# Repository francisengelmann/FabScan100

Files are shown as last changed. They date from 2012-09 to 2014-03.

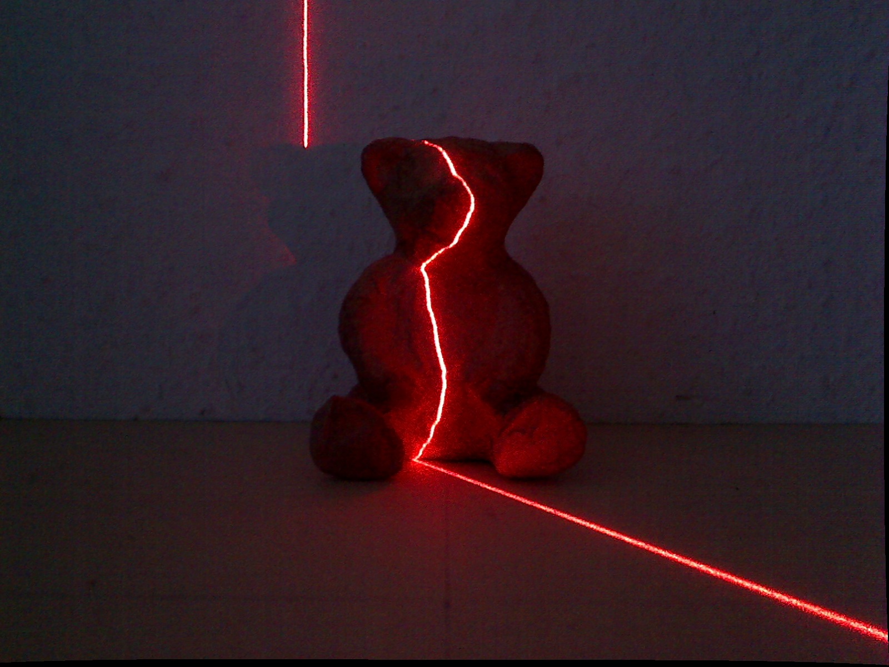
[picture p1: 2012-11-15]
qtTest/laser_on.jpg

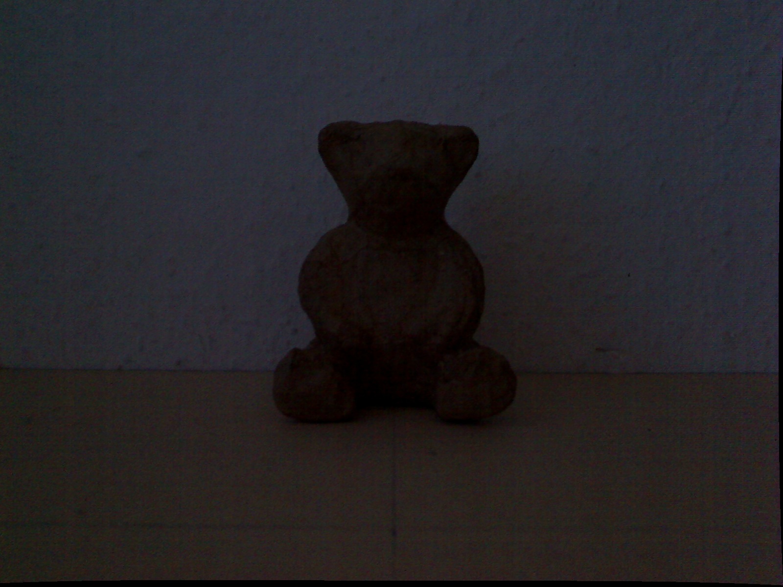
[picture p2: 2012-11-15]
qtTest/laser_off.jpg

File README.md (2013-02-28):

FabScan100
==========
The FabScan100 software is planned to run on Mac and Linux (and maybe also Windows).
This git repository stores all the files for the project, software as well as the hardware.

Also check these links for more information:
* http://hci.rwth-aachen.de/fabscan100
* http://groups.google.com/group/fabscan

Progress
========

FabScan100 is now functional! Runs on Mac and Ubuntu, still needs to be ported to Windows.

Current Setup on Mac: Qt 5.0.1 with Qt-Creator 2.6.2

Current Setup on Ubuntu: Qt 5.0.1 with Qt-Creator 2.6.2 

Current Setup on Windows: not tested, who wants to do this ?

Qt 4.8 is needed for QGLFunctions.

Installation
===========

Install "Qt Creator" and "Qt Libraries Qt 5.0" from http://qt-project.org/downloads.
Make sure you have OpenGL installed. Preinstalled on Ubuntu, Mac. What about Windows?

Mac OS X 10.8.2 with XCode 4.6 installed
========================================
1. Install Homebrew: http://mxcl.github.com/homebrew/
The next steps need to be executed in Terminal.
Terminal is located in Applications/Utilities/Terminal.app
2. Install OpenCV using homebrew: brew install opencv
3. Install Boost: brew install boost
4. Install FLANN: brew install flann
5. Install VTK: brew install vtk
6. Install eigen: brew install eigen
7. Install the experimental version from trunck of PCL 1.7

  * svn co http://svn.pointclouds.org/pcl/trunk pcl-trunk
  * cd pcl-trunk && mkdir build && cd build
  * cmake -DCMAKE_BUILD_TYPE=Release .. 
  * make
  * sudo make install

At this point we have installed all the dependencies needed for FabScan. We can now proceed to actually compiling FabScan:

8. Install git which is a tool to access source repositories: brew install git
9. Then download the code using git: git clone git://github.com/francisengelmann/FabScan100.git
10. Open qtTest/qtTest.pro in "Qt Creator".
11. If asked select "Qt 5.0.1" Kit, then click "Configure Project".
12. In the left panel, click on "Projects", then "Manage Kits". Select from AutoDetected "Qt5.0.1", click clone, then in the "Compiler" popupmenu select "GCC x86 64bit". Then press OK to exit.
13. Again in the "Projects" tab, select the newly created Kit from the "Add Kit" popupmenu.
14. Run the project by clicking on the green arrow on the bottom left.
15. Wait for it to compile, this can take a few minutes.
 
Ubuntu 12.10:
=======
1. Install Qt
  * Install Qt-5.0.1 libraries http://qt-project.org/downloads

2. Install OpenCV (inspired from http://www.samontab.com/web/2012/06/installing-opencv-2-4-1-ubuntu-12-04-lts/)
  * sudo apt-get update
  * sudo apt-get upgrade
  * sudo apt-get install libeigen3-dev build-essential libgtk2.0-dev libjpeg-dev libtiff4-dev libjasper-dev libopenexr-dev cmake python-dev python-numpy python-tk libtbb-dev yasm libfaac-dev libopencore-amrnb-dev libopencore-amrwb-dev libtheora-dev libvorbis-dev libxvidcore-dev libx264-dev sphinx-common texlive-latex-extra libv4l-dev libdc1394-22-dev libavcodec-dev libavformat-dev libswscale-dev

  * cd ~
  * wget http://downloads.sourceforge.net/project/opencvlibrary/opencv-unix/2.4.4/OpenCV-2.4.4-beta.tar.bz2
  * tar -xvf OpenCV-2.4.4-beta.tar.bz2
  * cd OpenCV-2.4.4

  * mkdir build
  * cd build
  * cmake -D WITH_TBB=ON -D BUILD_NEW_PYTHON_SUPPORT=ON -D WITH_V4L=ON -D INSTALL_C_EXAMPLES=OFF -D INSTALL_PYTHON_EXAMPLES=OFF -D BUILD_EXAMPLES=OFF -D WITH_QT=ON -D WITH_OPENGL=ON ..
  
3. Install PCL
  * sudo add-apt-repository ppa:v-launchpad-jochen-sprickerhof-de/pcl
  * sudo apt-get update
  * sudo apt-get install libpcl-all

4. Install uvccapture
  * sudo apt-get install uvccapture
  * to test run the following command: uvccapture -d/dev/video0 -oshot.jpg

5. Give permissions for serial port
  * sudo adduser USER_NAME dialout
  * log out and back in

Windows:
========
People are working on this :)
 
Other platforms
===============

Make sure to adapt the .pro file e.g. correct lib and header pathes.

Get the source code
===================

In order to compile the code you need git:
Mac: brew install git
Ubunutu: sudo apt-get install git
Windows: ?

To get read-only access to the code, type into the console:
git clone git://github.com/francisengelmann/FabScan100.git

If you also want to modify the code please send me an email with your ssh public key so i can give you access.

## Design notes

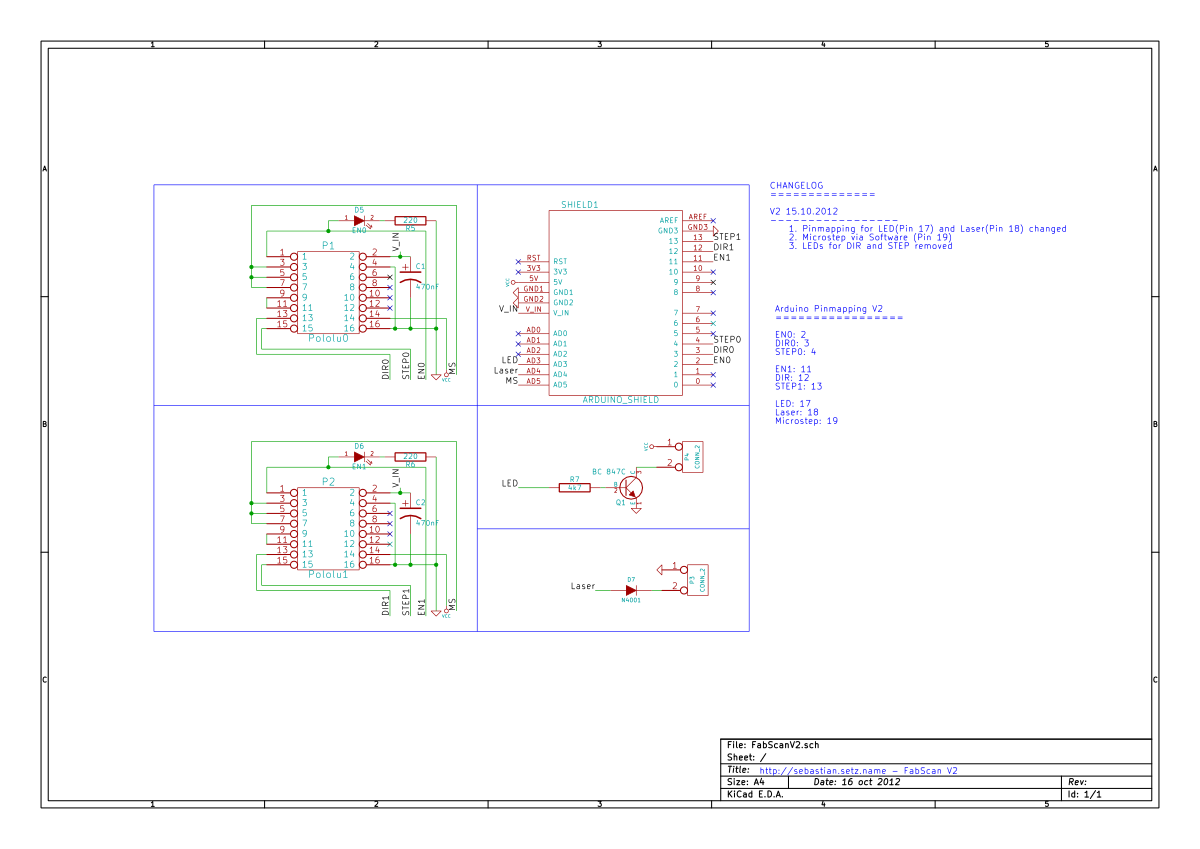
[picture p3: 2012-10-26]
arduino/FabScanModV2_Schematic.png

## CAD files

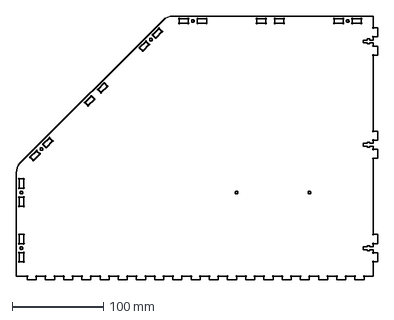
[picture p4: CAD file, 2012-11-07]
lasercutter/BoxLeftSide.dxf
397.0 x 290.0 mm

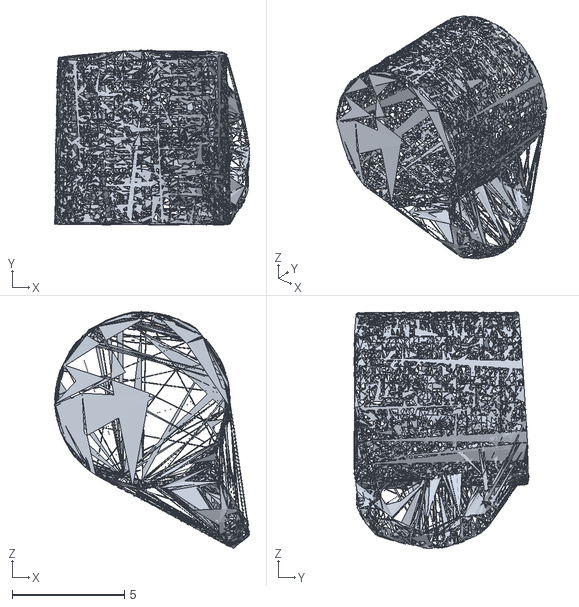
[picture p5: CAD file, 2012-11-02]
scans/bigCub/bigCub.stl
8.67 x 7.75 x 10.5

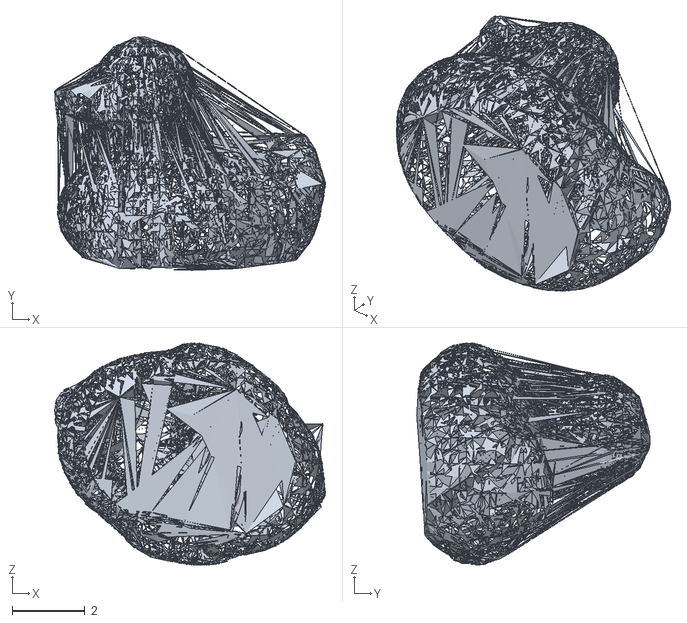
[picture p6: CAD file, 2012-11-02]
scans/bigDuck/bigDuck.stl
7.44 x 6.41 x 6.09

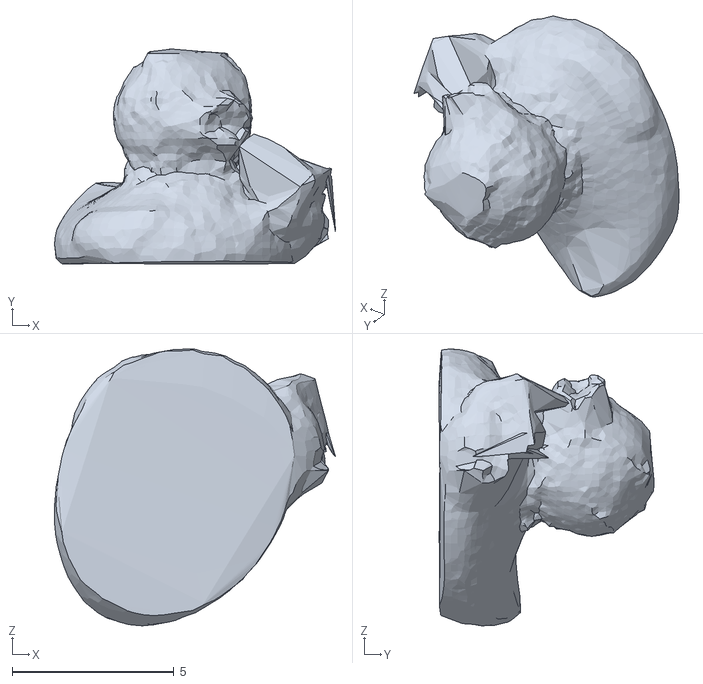
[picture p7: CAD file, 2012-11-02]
scans/laptopDuck/laptopDuck.ply
8.69 x 6.64 x 8.56

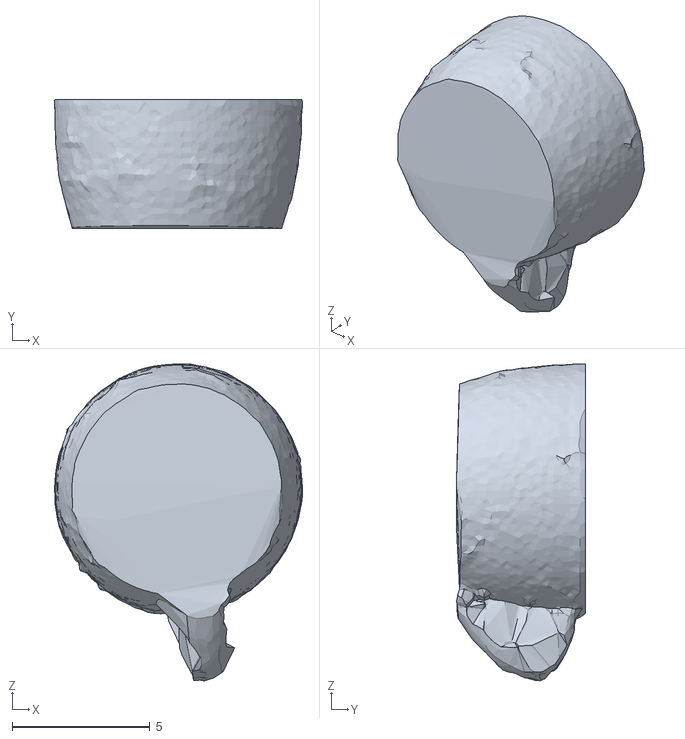
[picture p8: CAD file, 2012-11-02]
scans/ovalCub/ovalCub.ply
9.02 x 4.70 x 11.5

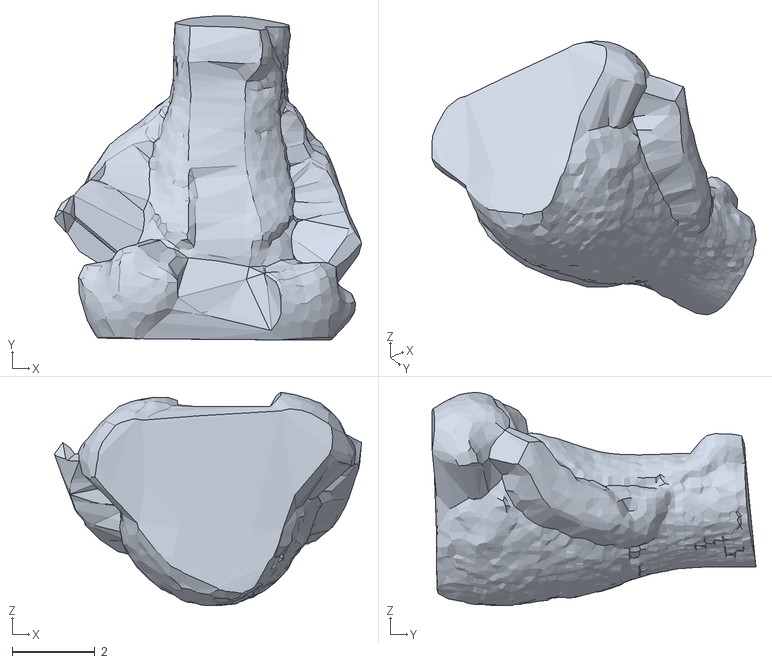
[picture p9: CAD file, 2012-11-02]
scans/smallDuck/smallDuck.ply
7.41 x 7.82 x 5.15

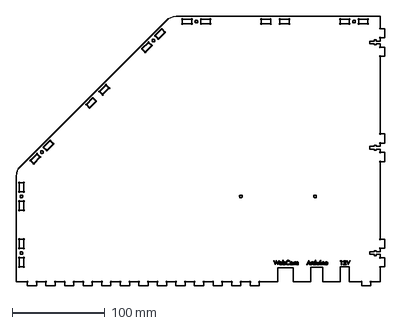
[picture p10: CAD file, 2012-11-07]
lasercutter/BoxRightSide.dxf
397.0 x 290.0 mm

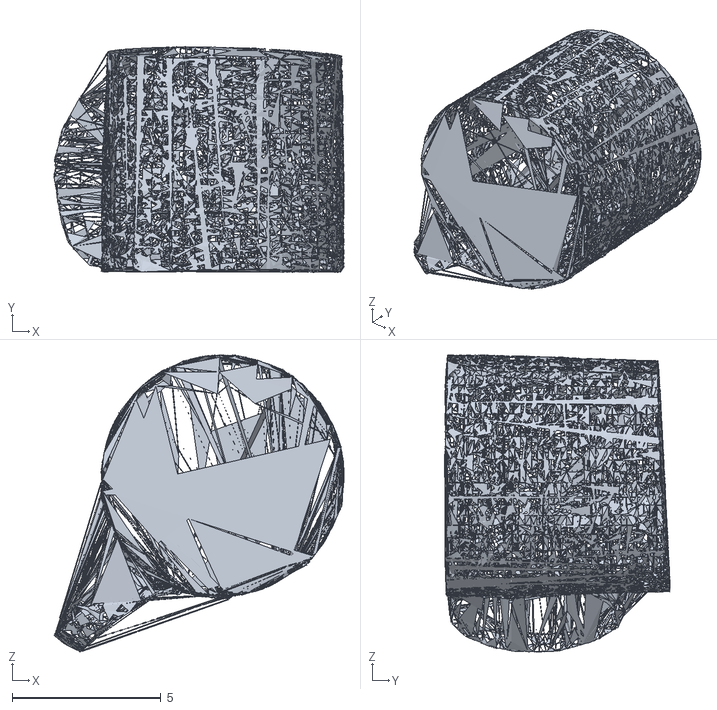
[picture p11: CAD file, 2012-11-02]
scans/bigCub/bigCub2.stl
9.75 x 7.57 x 9.98

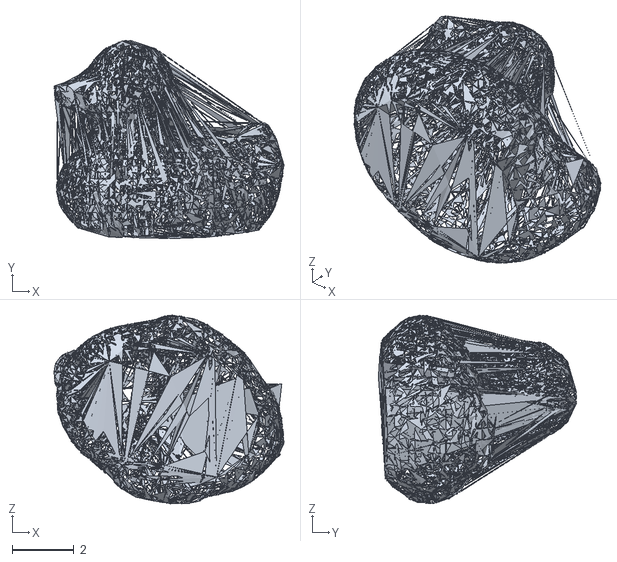
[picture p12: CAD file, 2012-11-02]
scans/bigDuck/bigDuck2.stl
7.44 x 6.41 x 6.09

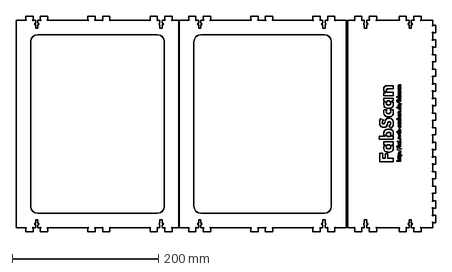
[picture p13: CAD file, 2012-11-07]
lasercutter/BoxTopSlopeFront.dxf
573.6 x 294.0 mm

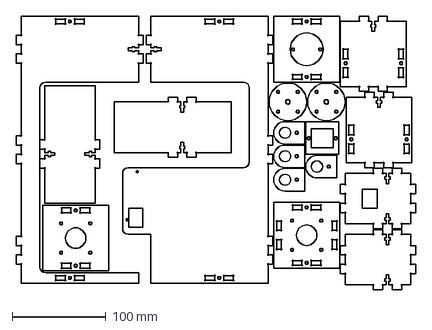
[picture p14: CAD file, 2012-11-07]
lasercutter/CamLaserTurnTableHolder.dxf
425.0 x 291.0 mm

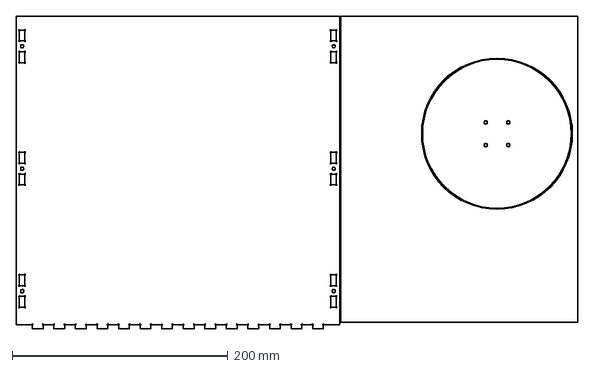
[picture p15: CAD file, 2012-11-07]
lasercutter/BoxBackMiddle.dxf
521.0 x 290.0 mm

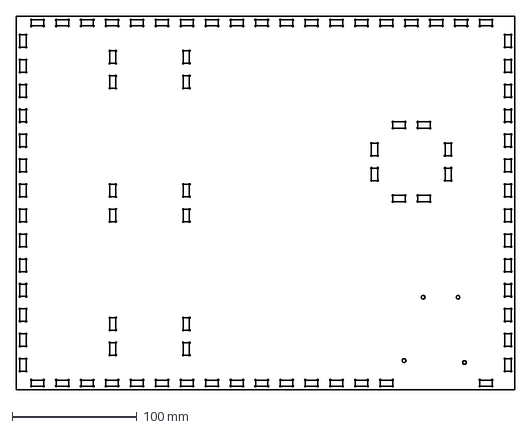
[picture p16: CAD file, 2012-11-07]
lasercutter/BoxBottom.dxf
400.0 x 300.0 mm

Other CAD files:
scans/bigCub/bigCub.ply
scans/bigCub/bigCub2.ply
scans/bigDuck/bigDuck.ply
scans/bigDuck/bigDuck2.ply

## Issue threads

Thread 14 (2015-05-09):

turntable is driving wrong every 8. scan-step

pointhi, 2015-05-09:
I'm using a fabcube, without a turnable laser, and found out that the turntable is driving in the opposit direction every 8. scan-step and then (holding the position/driving back) for 2 or 3 steps.

Because of that, I cannot scan objects in a correct way. For example, a scanned cuboid is more like a rectangle with rounded surfaces.

The software is build from the repository on Ubuntu 14.04.

mariolukas, 2015-05-09:
Mho sounds strange to me. Maybe there is a problem with you motor driver. Which hardware setup are you using? Fabscan Shield with Pololu motor driver?

pointhi, 2015-05-09:
I'm using the fabscan shield, but not the Pololu motor driver, because I get a SilentStepStick as replacement for the fault Polulu.

In the control panel the stepper is always working correctly, so I'm thinking the scanner software has some problem, or is expecting a stepper-motor for the laser.

pointhi, 2015-05-09:
ok, seems the overcurrent protection was configed to harsh, so the driver overheated and shut down for a few seconds (my therorie).

Correct behavior of the problem: 26 stepps, then 2 or 3 steps backward/stop, 8 steps normal, 2 or 3 steps backward/stop, 8 steps normal,....

mariolukas, 2015-05-09:
Have you soldered all pin headers to the silent step stick driver ?

pointhi, 2015-05-09:
no, I got an instruction pdf, in which was described how to solder the driver correctly

mariolukas, 2015-05-09:
I am using the silent step sticks with the new fabscan software. I is better if you do not connect EN, CFG1, CFG2 and CFG3.

pointhi, 2015-05-09:
In my pdf the silent step stick has only connected EN, STEP and DIR on the one side, on the other side all pins are connected

mariolukas, 2015-05-09:
Thats from the TMC2100 Datasheet and the reason why i keep EN open (no connection).

Y, ramp down from 100% to 34% motor current in 44M clock cycles (3 to 4 seconds) if no step pulse for more than 1M clock cycles (standstill). In combination with stealthChop be sure not to work with too low overall current setting, as regulation will not be able to measure the motor current after stand still current reduction. This will result in very low motor current after the stand-still period.

Closed 2015-05-09.

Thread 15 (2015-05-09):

support model-servo for movable laser instad of stepper motor

pointhi, 2015-05-09:
I don't know if the movable laser is already full suported, but probably it would be a good idea to support model-servos optional to stepper motors.

Advantages:

1.) Servomotors working with absolute positions, stepper-motors only with relative positions
2.) Servomotors are cheaper
3.) Servomotors are repositioning automatically
4.) Servomotors need less power

mariolukas, 2015-05-09:
That's a good suggestion, i already thought about that.
But this brach is deprecated. A first version of the new offical software will be released soon.
You will find further information soon at: http://hci.rwth-aachen.de/fabscanpi

pointhi, 2015-05-12:
Probably, I could create the required code-changes, as long as laser support is already implemented (I don't know if the lasermotor support is only for develop-purpose, or already working code).

thx

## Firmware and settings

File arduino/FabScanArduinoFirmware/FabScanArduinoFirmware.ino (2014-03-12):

// FabScan - http://hci.rwth-aachen.de/fabscan
//
//  Created by Francis Engelmann on 7/1/11.
//  Copyright 2011 Media Computing Group, RWTH Aachen University. All rights reserved.
//  
//  Chngelog:
//  R. Bohne 29.01.2013: changed pin mapping to Watterott FabScan Arduino Shield
//  R. Bohne 30.12.2013: added pin definitions for stepper 4 --> this firmware supports the new FabScan Shield V1.1, minor syntax changes. Steppers are now disabled at startup.
//  R. Bohne 12.03.2014: renamed the pins 14..19 to A0..A5 (better abstraction for people who use Arduino MEGA, etc.)

#define LIGHT_PIN A3
#define LASER_PIN A4
#define MS_PIN    A5

//Stepper 1 as labeled on Shield, Turntable
#define ENABLE_PIN_0  2
#define STEP_PIN_0    3
#define DIR_PIN_0     4

//Stepper 2, Laser Stepper
#define ENABLE_PIN_1  5
#define STEP_PIN_1    6
#define DIR_PIN_1     7

//Stepper 3, currently unused
#define ENABLE_PIN_2  11
#define STEP_PIN_2    12
#define DIR_PIN_2     13

//Stepper 4, currently unused
#define ENABLE_PIN_3  A0
#define STEP_PIN_3    A1
#define DIR_PIN_3     A2
  
#define TURN_LASER_OFF      200
#define TURN_LASER_ON       201
#define PERFORM_STEP        202
#define SET_DIRECTION_CW    203
#define SET_DIRECTION_CCW   204
#define TURN_STEPPER_ON     205
#define TURN_STEPPER_OFF    206
#define TURN_LIGHT_ON       207
#define TURN_LIGHT_OFF      208
#define ROTATE_LASER        209
#define FABSCAN_PING        210
#define FABSCAN_PONG        211
#define SELECT_STEPPER      212
#define LASER_STEPPER       11
#define TURNTABLE_STEPPER   10
//the protocol: we send one byte to define the action what to do.
//If the action is unary (like turnung off the light) we only need one byte so we are fine.
//If we want to tell the stepper to turn, a second byte is used to specify the number of steps.
//These second bytes are defined here below.

#define ACTION_BYTE         1    //normal byte, first of new action
#define LIGHT_INTENSITY     2
#define TURN_TABLE_STEPS    3
#define LASER1_STEPS        4
#define LASER2_STEPS        5
#define LASER_ROTATION      6
#define STEPPER_ID          7

int incomingByte = 0;
int byteType = 1;
int currStepper;


//current motor: turn a single step 
void step()
{
 if(currStepper == TURNTABLE_STEPPER){
   digitalWrite(STEP_PIN_0, LOW);
 }else if(currStepper == LASER_STEPPER){
   digitalWrite(STEP_PIN_1, LOW);
 }

 delay(3);
 if(currStepper == TURNTABLE_STEPPER){
   digitalWrite(STEP_PIN_0, HIGH);
 }else if(currStepper == LASER_STEPPER){
   digitalWrite(STEP_PIN_1, HIGH);
 }
 delay(3);
}

//step the current motor for <count> times
void step(int count)
{
  for(int i=0; i<count; i++){
    step();
  }
}

void setup() 
{ 
  // initialize the serial port
   Serial.begin(9600);
   pinMode(LASER_PIN, OUTPUT);
   pinMode(LIGHT_PIN, OUTPUT);
 
   pinMode(MS_PIN, OUTPUT);
   digitalWrite(MS_PIN, HIGH);  //HIGH for 16microstepping, LOW for no microstepping

  pinMode(ENABLE_PIN_0, OUTPUT);
  pinMode(DIR_PIN_0, OUTPUT);
  pinMode(STEP_PIN_0, OUTPUT);

  pinMode(ENABLE_PIN_1, OUTPUT);
  pinMode(DIR_PIN_1, OUTPUT);
  pinMode(STEP_PIN_1, OUTPUT);
 
  pinMode(ENABLE_PIN_2, OUTPUT);
  pinMode(DIR_PIN_2, OUTPUT);
  pinMode(STEP_PIN_2, OUTPUT);

  pinMode(ENABLE_PIN_3, OUTPUT);
  pinMode(DIR_PIN_3, OUTPUT);
  pinMode(STEP_PIN_3, OUTPUT);
 
 //disable all steppers at startup
 digitalWrite(ENABLE_PIN_0, HIGH);  //HIGH to turn off
 digitalWrite(ENABLE_PIN_1, HIGH);  //HIGH to turn off
 digitalWrite(ENABLE_PIN_2, HIGH);  //LOW to turn on
 digitalWrite(ENABLE_PIN_3, HIGH);  //LOW to turn on 
 
 digitalWrite(LIGHT_PIN, LOW); //turn light off

 digitalWrite(LASER_PIN, HIGH); //turn laser on
 Serial.write(FABSCAN_PONG); //send a pong back to the computer so we know setup is done and that we are actually dealing with a FabScan
 
 currStepper = TURNTABLE_STEPPER;  //turntable is default stepper
} 

void loop() 
{

  if(Serial.available() > 0){

    incomingByte = Serial.read();
    
    switch(byteType){
      case ACTION_BYTE:
      
          switch(incomingByte){    //this switch always handles the first byte
            //Laser
            case TURN_LASER_OFF:
              digitalWrite(LASER_PIN, LOW);    // turn the LASER off
              break;
            case TURN_LASER_ON:
              digitalWrite(LASER_PIN, HIGH);   // turn the LASER on
              break;
            case ROTATE_LASER: //unused
              byteType = LASER_ROTATION;
              break;
            //TurnTable
            case PERFORM_STEP:
              byteType = TURN_TABLE_STEPS;
              break;
            case SET_DIRECTION_CW:
              if(currStepper == TURNTABLE_STEPPER){
                digitalWrite(DIR_PIN_0, HIGH);
              }else if(currStepper == LASER_STEPPER){
                digitalWrite(DIR_PIN_1, HIGH);
              }
              break;
            case SET_DIRECTION_CCW:
              if(currStepper == TURNTABLE_STEPPER){
                digitalWrite(DIR_PIN_0, LOW);
              }else if(currStepper == LASER_STEPPER){
                digitalWrite(DIR_PIN_1, LOW);
              }
              break;
            case TURN_STEPPER_ON:
              if(currStepper == TURNTABLE_STEPPER){
                digitalWrite(ENABLE_PIN_0, LOW);
              }else if(currStepper == LASER_STEPPER){
                digitalWrite(ENABLE_PIN_1, LOW);
              }
              break;
            case TURN_STEPPER_OFF:
              if(currStepper == TURNTABLE_STEPPER){
                digitalWrite(ENABLE_PIN_0, HIGH);
              }else if(currStepper == LASER_STEPPER){
                digitalWrite(ENABLE_PIN_1, HIGH);
              }
              break;
            case TURN_LIGHT_ON:
              byteType = LIGHT_INTENSITY;
              break;
            case TURN_LIGHT_OFF:
              digitalWrite(LIGHT_PIN, LOW);
              break;
            case FABSCAN_PING:
              delay(1);
              Serial.write(FABSCAN_PONG);
              break;
            case SELECT_STEPPER:
              byteType = STEPPER_ID;
              break;
            }
      
          break;
       case LIGHT_INTENSITY:       //after this point we take care of the second byte if one is sent
          analogWrite(LIGHT_PIN, incomingByte);
          byteType = ACTION_BYTE;  //reset byteType
          break;
        case TURN_TABLE_STEPS:
          step(incomingByte);
          byteType = ACTION_BYTE;
          break;
        case STEPPER_ID:
          Serial.write(incomingByte);
          currStepper = incomingByte;
          byteType = ACTION_BYTE;
          break;
    }
  } 
} 

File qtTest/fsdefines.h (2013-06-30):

#ifndef FSDEFINES_H
#define FSDEFINES_H

#define MC_TURN_LASER_OFF      200
#define MC_TURN_LASER_ON       201
#define MC_PERFORM_STEP        202
#define MC_SET_DIRECTION_CW    203
#define MC_SET_DIRECTION_CCW   204
#define MC_TURN_STEPPER_ON     205
#define MC_TURN_STEPPER_OFF    206
#define MC_TURN_LIGHT_ON       207
#define MC_TURN_LIGHT_OFF      208
#define MC_ROTATE_LASER        209
#define MC_FABSCAN_PING        210
#define MC_FABSCAN_PONG        211
#define MC_SELECT_STEPPER      212
#define MC_LASER_STEPPER       11
#define MC_TURNTABLE_STEPPER   10

#define REALLY_BIG_NUMBER     99999
#define REALLY_SMALL_NUMBER  -99999

//to make the scanning process faster we ommit the lower and hight part of the cvImage
//as there is no object anyway.  The lower limit is defined by the turning table lower bound
//units are pixels, seen from the top, resp from the bottom
/*
#define UPPER_ANALYZING_FRAME_LIMIT 0
#define LOWER_ANALYZING_FRAME_LIMIT 30

//as the actual position in the frame differs a little from calculated laserline we stop a little befor as we might catch the real non reflected laser line which creates noise
#define ANALYZING_LASER_OFFSET 90

//defining the origin in the cvFrame
//the position of intersection of back plane with ground plane in cvFrame in percent
//check the yellow laser line to calibrate, the yellow laser line should touch the bottom plane
//#define ORIGIN_Y 0.825
#define ORIGIN_Y 0.75

#define DELAY_UNTIL_CAM_SHOT 0

//logitech c270
#define FRAME_WIDTH 26.6f //in cm. the width of what the camera sees, ie place a measure tool at the back-plane and see how many cm the camera sees.
#define CAM_IMAGE_WIDTH 1280.0f
#define CAM_IMAGE_HEIGHT 960.0f //here I am not sure, i think it is 960, (old=853.0f)


//position of the laser
#define LASER_POS_X 14.0f //precise by construction
#define LASER_POS_Y 6.4f  //not needed/used for calculations
#define LASER_POS_Z 28.8f //precise by construction

#define LASER_SWIPE_MIN 18.0f
#define LASER_SWIPE_MAX 52.0f

//position of the c270
#define CAM_POS_X 0.0f //precise by construction
//#define CAM_POS_Y 4.07f
#define CAM_POS_Y 5.57f
#define CAM_POS_Z 30.9f

//position of the turntable
#define TURNTABLE_POS_X 0.0f //not used by calculations
#define TURNTABLE_POS_Y 0.0f //not used by calculations
#define TURNTABLE_POS_Z 7.5f //precise by construction
*/

#endif // FSDEFINES_H

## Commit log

2012-11-02 added a few example scans
    [bigCub.ply, bigCub.stl, bigCub2.ply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]
2012-11-02 added most recent lasercutter parts
2012-11-02 added gitignore
    [mesh.ply]
2012-11-02 colors on pcl coming
    [mesh.ply]
2012-11-07 added .dxf files
    [BoxBackMiddle.dxf, BoxBottom.dxf, BoxLeftSide.dxf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]
2012-11-08 added camera menu
2012-11-12 updated Arduino Sketch
2012-11-13 stepper should now work properly
2012-11-14 renamed stepper to turntable
2012-11-15 adding laser test images
2012-11-22 add assembly instructions
2012-11-26 updated assembly instructions
2013-01-30 camera working
2013-01-30 fixed qt5 related bug
    [main.cpp]
2013-02-17 added ply import functionality, changed gui of control panel, added a few alert messages when camera is not connected
2013-06-20 fixed bug with powercrust
2013-06-21 cleaned up code a little, put export stl button to menu
2013-06-21 removed unused slots
2013-06-21 improved code for powercrust, changed gui for dialog a little, other small improvment
2013-06-30 local changes, renames stl export menu
2013-12-30 This sketch tests all four stepper drivers on the FabScan-Shield V1.1
2013-12-30 The test sketch now blinks all leds/light/laser a few times and after this, starts spinning the motors
2013-12-30 firmware: minor syntax changes and steppers are now disabled at startup.
2014-01-13 compiles under 10.8.5. switched to pcl1.7, qextserialport-1.2rc and fixed some memory allocs
2014-01-13 set default stack size to 32MB. Maybe fixes #5
    [main.cpp]
2014-03-12 changed pin names 14..19 to A0..A5
